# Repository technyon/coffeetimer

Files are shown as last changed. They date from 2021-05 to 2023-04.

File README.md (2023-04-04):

# coffeetimer
My coffee grinder, the Macap M2D has an adjustable timer built-in. However, some genius of product designer but the knob to adjust the time at the bottom side of the grinder. To adjust it you have to lift the device (which is quite heave), and then adjust it, usually holding it in an awkward position.

To remedy this, I added a microcontroller with a display and a rotary encoder. As a plus, time can now be adjusted with 100 millisecond accuracy, as opposed to the unreliable built-in method which uses an analog potentiometer.

This project includes the firmware for the microcontroller and 3D-printed parts which replace the bottom part of the grinder. The display and rotary encoder are mounted on the right side of the grinder.

If you need help building this, don't hesitate to ask.

# A word of caution

Modding your grinder requires working on the motor power system, which works with mains power. Mains power is dangerous and there's danger to receive a potentially lethal electric shock. Furthermore, fire can be the result of incorrectly wiring the motor. Only do this mod if you know what you are doing! If not, ask someone who does.

Also, please read the paragraph about liability in the provided LICENSE file.

# Compilation

### Prerequisites
- Arduino SDK. Unpack and set ARDUINO_SDK_PATH to its location (e. g. export ARDUINO_SDK_PATH="/usr/share/arduino-1.8.13/")
- ESP32 SDK for Arduino: https://raw.githubusercontent.com/espressif/arduino-esp32/gh-pages/package_esp32_index.json. Add the URL in the Arduino SDK board manager and enable the ESP32 SDK (Version 1.0.6 as ofo the time of writing)
- Arduino cmake toolchain: https://github.com/technyon/Arduino-CMake-Toolchain. Unpack to a location of your choice
- cmake

### Running cmake
In the pzemctl directory, create a cmake build directory in change into it.

- cmake -D CMAKE_TOOLCHAIN_FILE=/path/to/Arduino-toolchain.cmake ..
- You will get an error that the board is not selected.
- Run "ccmake ..". As ARDUINO_BOARD, select "ESP32 Dev Module [esp32.esp32]"
- Press c to configure. New options for the ESP32 appear
- Set "Arduino(esp32.esp32)/Partition" to "No OTA (1MB APP/3MB SPIFFS)"
- cmake -D CMAKE_TOOLCHAIN_FILE=/usr/share/Arduino-CMake-Toolchain/Arduino-toolchain.cmake -D ARDUINO_BOARD_OPTIONS_FILE=BoardOptions.cmake ..

cmake should now be setup. Run make to compile.

# Hardware
You need:

- An ESP32
- A Relais
- A USB Power Supply.
- An SSD1306 OLED display
- A rotary encoder
- A big capacitor to stabilize the power supply for the ESP (I used 4700 µF, less might work)
- Cold appliance socket
- M3 and M2 screws, nuts and washers
- Copper tape for EMI shielding
- Feet for the new base

These are the parts I used:
- ESP32 D1 mini: https://www.amazon.de/gp/product/B08BTLYSTM/
- SSD1306 OLED: https://www.amazon.de/gp/product/B0777HHQDT/
- Relais: https://www.amazon.de/gp/product/B07V1X2RSP/
- Rotary encoder: https://www.ebay.de/itm/283974309391 (any other should work, just check it's the right size)
- Cold appliance socket: https://www.amazon.de/gp/product/B004S7RWSY/
- Base feet: https://www.amazon.de/gp/product/B07D4GHGR3/

# Wiring

- The rotary encoder connects to 3.3V and Pins 26 and 27
- The rotary encoder push button connects to ground and pin 33
- The Relais connects to 5v, GND and pin 25
- The grinders switch connects to GND and pin 32
- The display connects to 3.3v, GND, and I2c (Pin 21 for SDA, Pin 22 for SCL)

# 3D Parts

Print all parts. The temporary support can be used to attach the controls part to the lower base.
The upper base part needs to be EMI shielded. Cover all of the underside with copper tape and connect it to ground (Mains power PE). Also cover the capacitor support upper side and connect to PE.

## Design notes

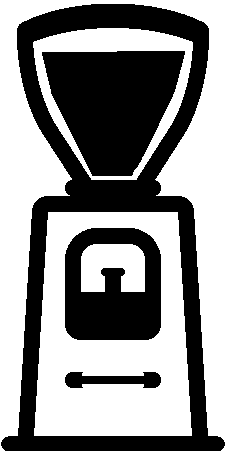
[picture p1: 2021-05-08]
resources/images/fill_fullsize.png

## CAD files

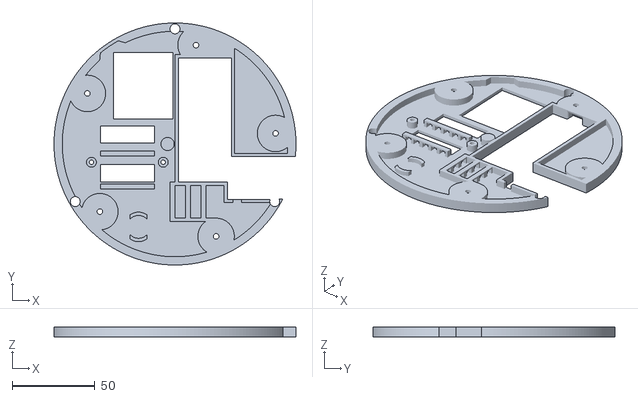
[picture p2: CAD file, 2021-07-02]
3d_print/macap base lower.stl
146.0 x 146.0 x 6.00

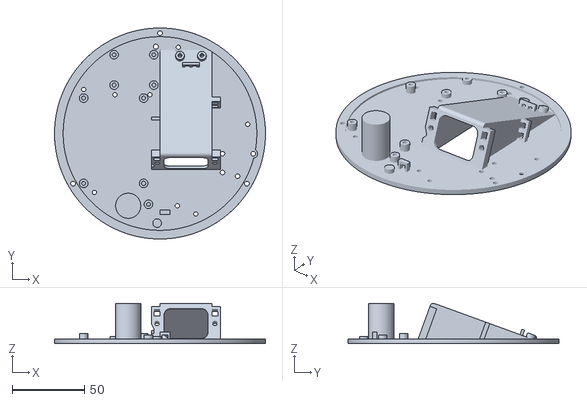
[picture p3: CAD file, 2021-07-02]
3d_print/macap base.stl
146.0 x 146.0 x 28.0

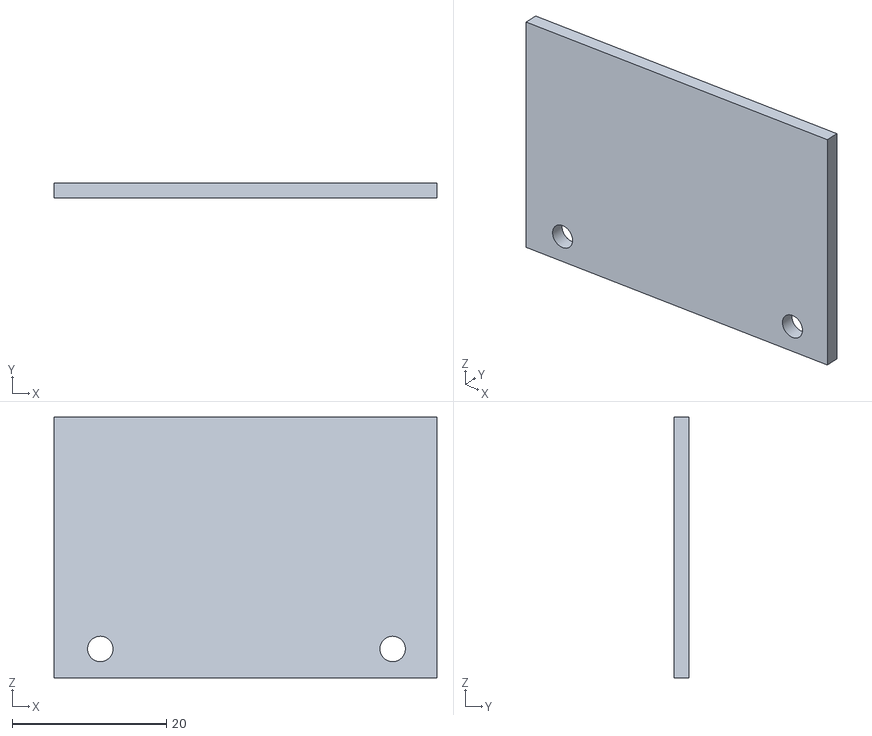
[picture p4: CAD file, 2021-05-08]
3d_print/Lid.stl
49.7 x 2.00 x 33.8

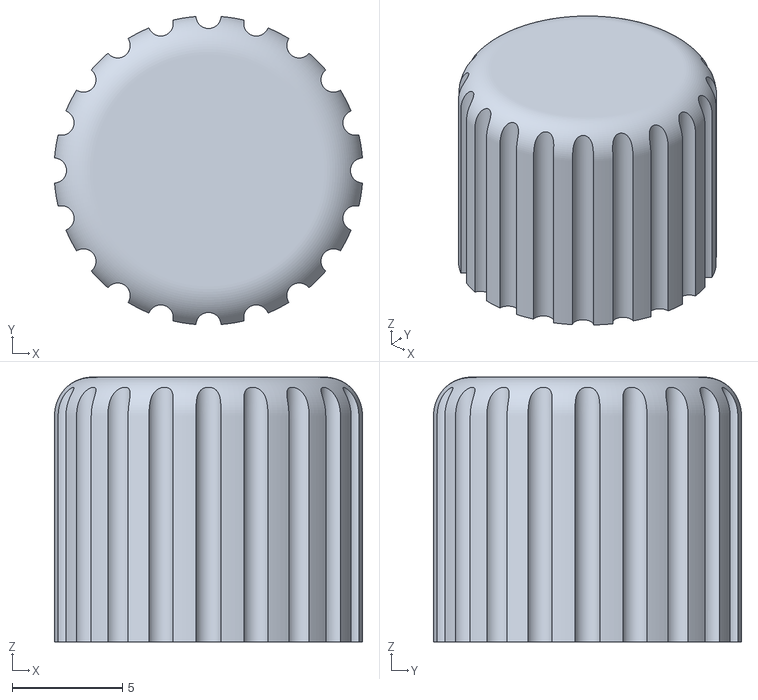
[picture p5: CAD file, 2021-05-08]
3d_print/Macap digital knob.stl
14.0 x 14.0 x 12.0

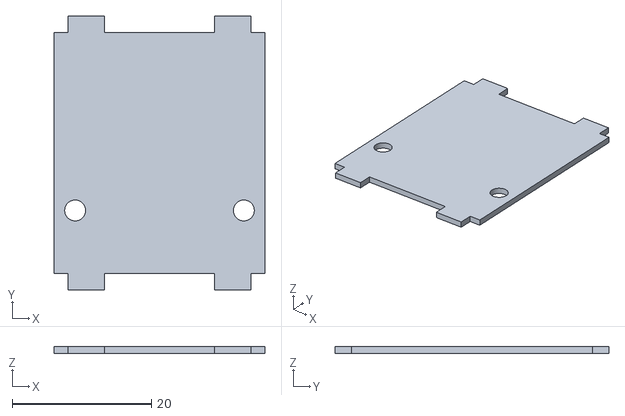
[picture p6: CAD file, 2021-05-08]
3d_print/Power supply isolation.stl
30.2 x 39.3 x 1.00

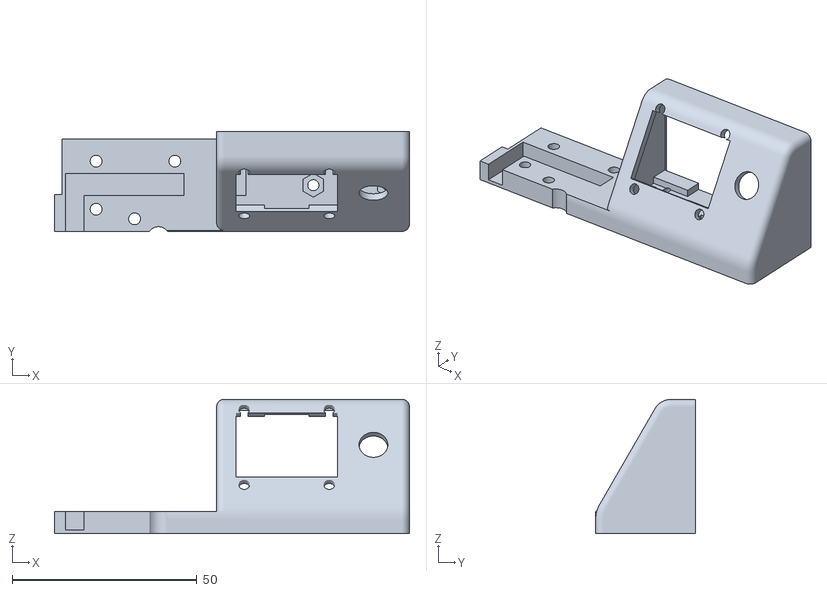
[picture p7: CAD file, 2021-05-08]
3d_print/macap controls.stl
96.0 x 27.0 x 36.3

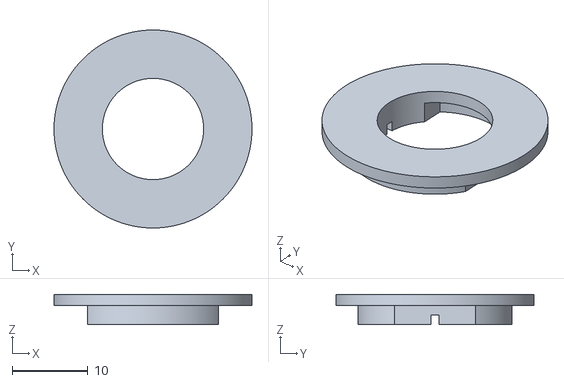
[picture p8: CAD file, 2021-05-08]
3d_print/Capacitor isolation bottom.stl
26.2 x 26.2 x 4.00

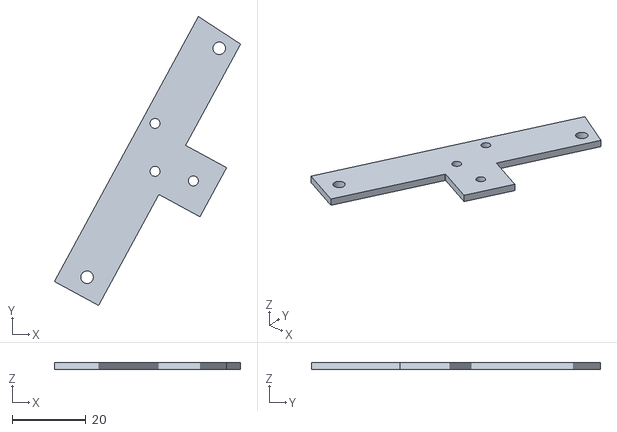
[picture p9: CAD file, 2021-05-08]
3d_print/Temporary Controls support.stl
50.5 x 78.4 x 2.00

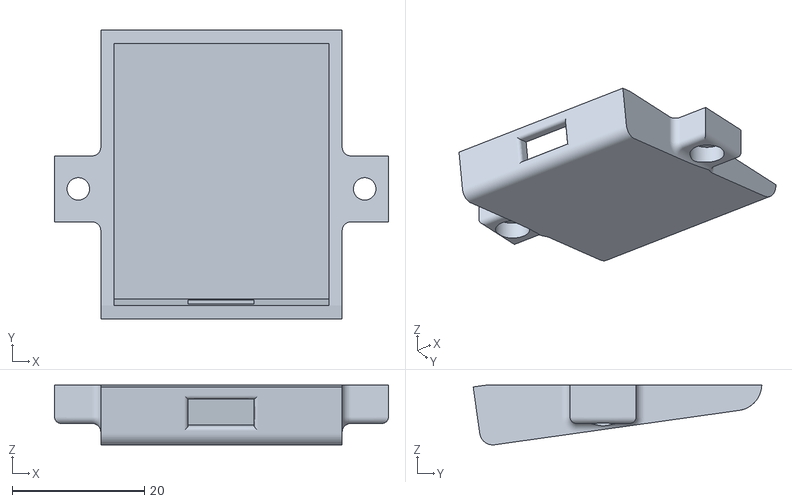
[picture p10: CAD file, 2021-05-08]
3d_print/ESP32.stl
50.5 x 43.6 x 9.04

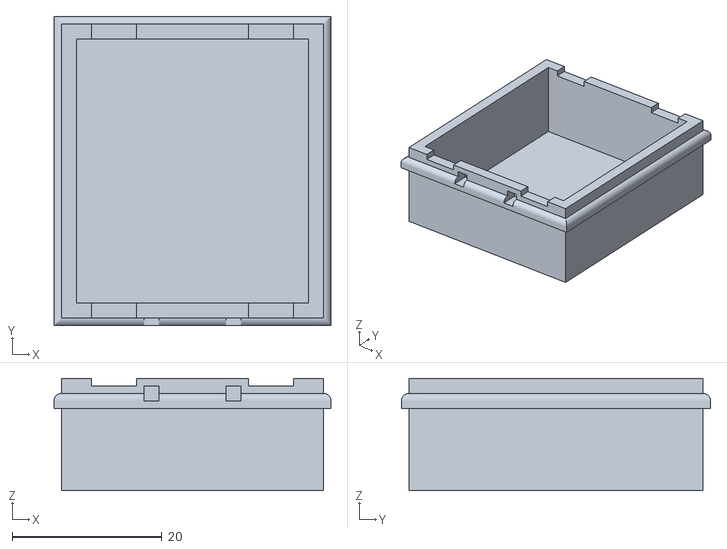
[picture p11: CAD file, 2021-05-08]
3d_print/Power supply.stl
37.0 x 41.3 x 15.0

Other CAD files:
3d_print/Macap digital knob.f3d
3d_print/Macap digital.f3z

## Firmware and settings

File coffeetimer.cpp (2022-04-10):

#include "Arduino.h"
#include "Config.h"
#include "Display.h"
#include <AiEsp32RotaryEncoder.h>
#include "Storage.h"
#include "MotorControl.h"



Display* display;
AiEsp32RotaryEncoder* encoder;
Storage* storage;
MotorControl* motorControl;

void onEncoderButtonPressed()
{
    if(motorControl->currentState() != MotorControlState::Off)
    {
        return;
    }
    Serial.println("PRESS");
}

void setup()
{
    pinMode(START_BUTTON_PIN, INPUT_PULLUP);

    display = new Display();
    display->initialize();

    motorControl = new MotorControl(display);

    Serial.begin(9600);
	Serial.println("START");

    storage = new Storage();

    Serial.println(storage->duration());


    encoder = new AiEsp32RotaryEncoder(ROTARY_ENCODER_A_PIN, ROTARY_ENCODER_B_PIN, ROTARY_ENCODER_BUTTON_PIN, ROTARY_ENCODER_VCC_PIN, ROTARY_ENCODER_STEPS);
    encoder->begin();

    encoder->setup(
            [] { encoder->readEncoder_ISR(); },
            onEncoderButtonPressed);

    encoder->setBoundaries(MINIMUM_DURATION * 10, MAXIMUM_DURATION * 10, false);
    encoder->setAcceleration(ROTARY_ENCODER_ACCELERATION);

    encoder->setEncoderValue(storage->duration() * 10);
    motorControl->setDuration(storage->duration());
}

void queryEncoder()
{
    //dont print anything unless value changed
    if (!encoder->encoderChanged())
    {
        return;
    }

    float duration = (float)encoder->readEncoder() / (float)10;
    display->setDuration(duration);
    motorControl->setDuration(duration);
    storage->setDuration(duration);
}

long lastDisplayUpdate = 0;

void loop()
{
    queryEncoder();

    long ts = millis();

    if(ts - lastDisplayUpdate > 50)
    {
        display->update();
        lastDisplayUpdate = ts;
    }

    if(digitalRead(START_BUTTON_PIN) == LOW)
    {
        motorControl->buttonPressed();
        storage->save();
    }
    else
    {
        motorControl->buttonReleased();
    }

    if(motorControl->currentState() == MotorControlState::Off)
    {
        encoder->enable();
    }
    else
    {
        encoder->disable();
    }

    motorControl->update();
}

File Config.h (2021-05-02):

#pragma once

// Minimum and maximum duration in seconds
#define MINIMUM_DURATION 0.5
#define MAXIMUM_DURATION 9

#define START_BUTTON_PIN 32
#define RELAIS_PIN 25

#define ROTARY_ENCODER_A_PIN 26
#define ROTARY_ENCODER_B_PIN 27
#define ROTARY_ENCODER_BUTTON_PIN 33
#define ROTARY_ENCODER_VCC_PIN -1

#define ROTARY_ENCODER_ACCELERATION 20

//depending on your encoder - try 1,2 or 4 to get expected behaviour
#define ROTARY_ENCODER_STEPS 4

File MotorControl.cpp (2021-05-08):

#include "MotorControl.h"
#include <Arduino.h>
#include "Config.h"

MotorControl::MotorControl(Display* display)
  : _display(display)
{
    pinMode(RELAIS_PIN, OUTPUT);
    disableRelais();
}

void MotorControl::buttonPressed()
{
    _isPressed = true;
}

void MotorControl::buttonReleased()
{
    _isPressed = false;
}

void MotorControl::setDuration(const float& value)
{
    _duration = value;
}

void MotorControl::update()
{
    switch(_state)
    {
        case MotorControlState::Off:
            _progress = 100;
            _display->setProgress(_progress);
            _display->setTimeLeft(_duration);
            if(_isPressed)
            {
                switchState(MotorControlState::On);
            }
            break;
        case MotorControlState::On:
            _progress = ((float)(_endMillis - millis()) / (float)(_endMillis - _startMillis)) * (float)100;
            _display->setProgress(_progress);
            _timeLeft = _endMillis >= millis() ? (_endMillis - millis()) / (float)1000 : 0;
            _display->setTimeLeft(_timeLeft);

            if(millis() >= _endMillis)
            {
                switchState(MotorControlState::PreOff);
            }

            if(!_isPressed)
            {
                switchState(MotorControlState::Interrupted);
            }
            break;
        case MotorControlState::Interrupted:
            if(millis() >= _timeOut)
            {
                switchState(MotorControlState::Off);
            }
            if(_isPressed)
            {
                switchState(MotorControlState::On);

                // override time values from on state
                int durationMillis = _duration * (float)1000;
                _startMillis = millis() - (durationMillis - _millisLeftAtInterruption);
                _endMillis = _startMillis + durationMillis;
            }
            break;
        case MotorControlState::PreOff:
            _display->setProgress(0);
            _display->setTimeLeft(0);
            if(_timeOut == -1)
            {
                _timeOut = millis() + 1000;
            }
            if(millis() >= _timeOut && !_isPressed)
            {
                switchState(MotorControlState::Off);
            }
            break;
    }
}

void MotorControl::switchState(const MotorControlState &state)
{
    switch(state)
    {
        case MotorControlState::Off:
        {
            // do nothing
            break;
        }
        case MotorControlState::On:
        {
            _startMillis = millis();
            _endMillis = _startMillis + (long)((float)1000 * _duration);
            enableRelais();
            _display->easeStatusLine(STATUS_LINE_EASE_TIME, STATUS_LINE_LENGTH);
            break;
        }
        case MotorControlState::Interrupted:
        {
            _millisLeftAtInterruption = _endMillis - millis();
            _timeOut = millis() + INTERRUPTED_STATE_TIMEOUT;
            _startMillis = -1;
            _endMillis = -1;
            disableRelais();
            _display->easeStatusLine(INTERRUPTED_STATE_TIMEOUT, 0);
            break;
        }
        case MotorControlState::PreOff:
        {
            _startMillis = -1;
            _endMillis = -1;
            _timeOut = -1;
            disableRelais();
            _display->easeStatusLine(STATUS_LINE_EASE_TIME, 0);
            break;
        }
        default:
        {
            Serial.print("MotorControl switchState(): Unhandled State ");
            Serial.println((int)state);
        }
    }

    _state = state;
}

void MotorControl::enableRelais()
{
    digitalWrite(RELAIS_PIN, HIGH);
    _display->grinderEnabled();
}

void MotorControl::disableRelais()
{
    digitalWrite(RELAIS_PIN, LOW);
    _display->grinderDisabled();
}

float MotorControl::timeLeft()
{
    return _timeLeft;
}

int MotorControl::progress()
{
    return _progress;
}

MotorControlState MotorControl::currentState()
{
    return _state;
}

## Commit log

2021-03-31 add rotary encoder
2021-04-10 add MotorControl class
2021-04-10 basic timed motor control works
2021-05-03 disable encoder while motor is running
2021-05-03 fix wrong type bug
    [MotorControl.cpp, coffeetimer.cpp]
2021-05-03 bugfix: unnecessary save after restart fixed
    [Storage.cpp]
2021-05-08 add 3d print filres
    [Capacitor isolation bottom.stl, ESP32.stl, Lid.stl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]
2021-07-02 update CAD files
    [Macap digital.f3z, macap base lower.stl, macap base.stl]
2022-04-10 Set arduino board variable to ESP32 devkit
